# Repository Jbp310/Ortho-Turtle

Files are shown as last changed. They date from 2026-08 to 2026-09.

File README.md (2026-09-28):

# Ortho-Turtle

Ortho-Turtle is an ortholinear keyboard designed by me,  Fastturtle, for Hackclub's KEEB project.

**If you want to make this yourself, just grab the files from Production-Ready_Files, and you should be good to go.** 

# Design Philosophies:

Keyboard Layout:
I went for a fairly unique layout with this keyboard, as not only is it a ortholinear layout, but it's a fairly nonstandard amount of keys (81). My main motivator behind choosing the keys was having all the keys that I usually use, plus the ones that I would require to navigate an environment without a mouse, as I frequent janky linux distros.

PCB:
I designed my keyboard PCB fairly basically, as it's the first circuit board I've ever designed. I chose to use surface mount diodes, to give the keyboard a cleaner look, and to challenge my soldering skills a bit. Other than that though it's not particularly unique, although I'm quite happy with the design, especially with it being the first one I've made.

Case:
I chose to 3d print the case so that I could have more options when it comes to customizing it, additionally, it saves a lot of cost, as I'm able to use materials I have on hand, vs having to utilize grant funds. As for the actual case design I made a nice and simple tray mount, with a plate, to make it easier to 3d print. I plan on O-ring mounting the PCB to ensure a nicer, and more consistent typing experience.

# Things I learned:

I think the main lesson I learned throughout the development of this project was the importance of having a concrete idea of what you want before you start. As I could have saved a fair bit of time spent redesigning if I had just decided upon an idea to begin with. In addtition I also learned how to utilize KiCad.

# Credits

First of all, lots of thanks to Miles and the amazing team at Hackclub that helped put KEEB together, because without KEEB this project never would have been possible.

Secondly, thank you to Scotto Keebs for all the amazing guides on making custom keyboards.

Finally, me, I did design this whole keyboard, so you know, don't steal it, if have issues or questions just let me know, I'm always happy to help!

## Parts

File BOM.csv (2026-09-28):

Item | description | price | link
Keyboard Switches | Silent Tactile HMX Bluestar switches 90pcs | 33.26 | https://www.aliexpress.us/item/3256811672963963.html?curPageLogUid=IBwGcwixCsqs
Hotswap Sockets | Kailh hotswap sockets | 27.40 | https://www.aliexpress.us/item/3256804467765065.html?curPageLogUid=3ppgSUzBQ6wf
Screws | m3x10 screws for securing the PCB | 1.09 | https://www.aliexpress.us/item/3256808598917048.html?curPageLogUid=O4cSqPpW1uUs
Stabilizers | Screw in stabilizers for the keyboard | 1.09 | https://www.aliexpress.us/item/3256807050530252.html?curPageLogUid=OPPUPFXyg6cH
Keycaps | Double shot PBT keycaps for the keyboard | 9.64 | https://www.aliexpress.us/item/3256804350819353.html?curPageLogUid=l2Hzkh5qw7W4
PCB | The keyboard PCB | 24.30 | https://jlcpcb.com/
Orpheus Pico | Fancy Pi pico | unknown | N/A
Diodes | CDBW140-G Diodes from Comchip Technology SOD-123 Diodes | 14.29 | https://www.digikey.com/en/products/detail/comchip-technology/CDBW140-G/3308555

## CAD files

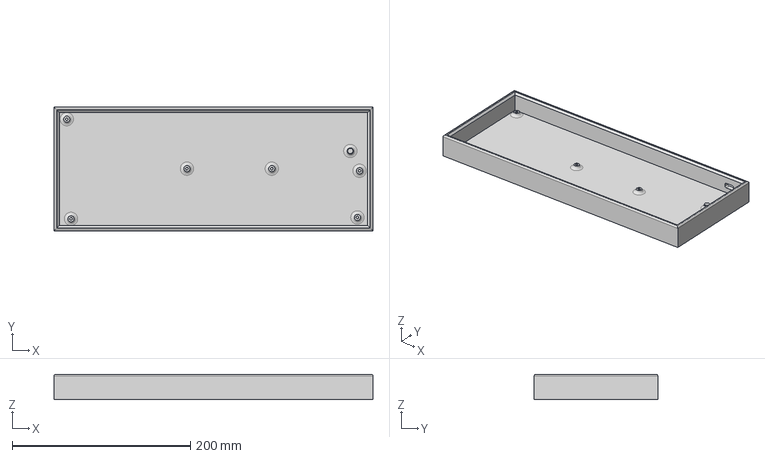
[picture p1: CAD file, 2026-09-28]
Case/Case.step
358.1 x 139.0 x 28.5 mm

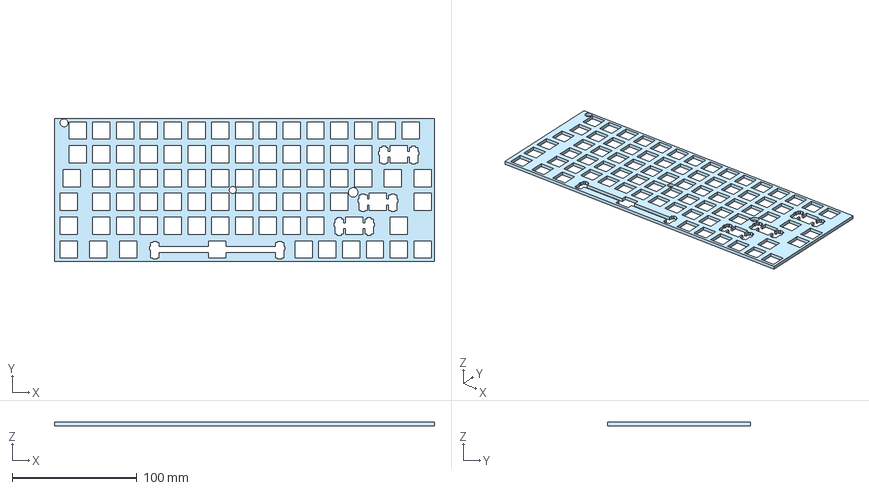
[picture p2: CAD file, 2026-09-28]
Case/Plate.step
304.2 x 114.3 x 3.00 mm

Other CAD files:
Production-Ready_Files/OrthoTurtle-Case.stl
Production-Ready_Files/Ortho-Turtle-Plate.stl

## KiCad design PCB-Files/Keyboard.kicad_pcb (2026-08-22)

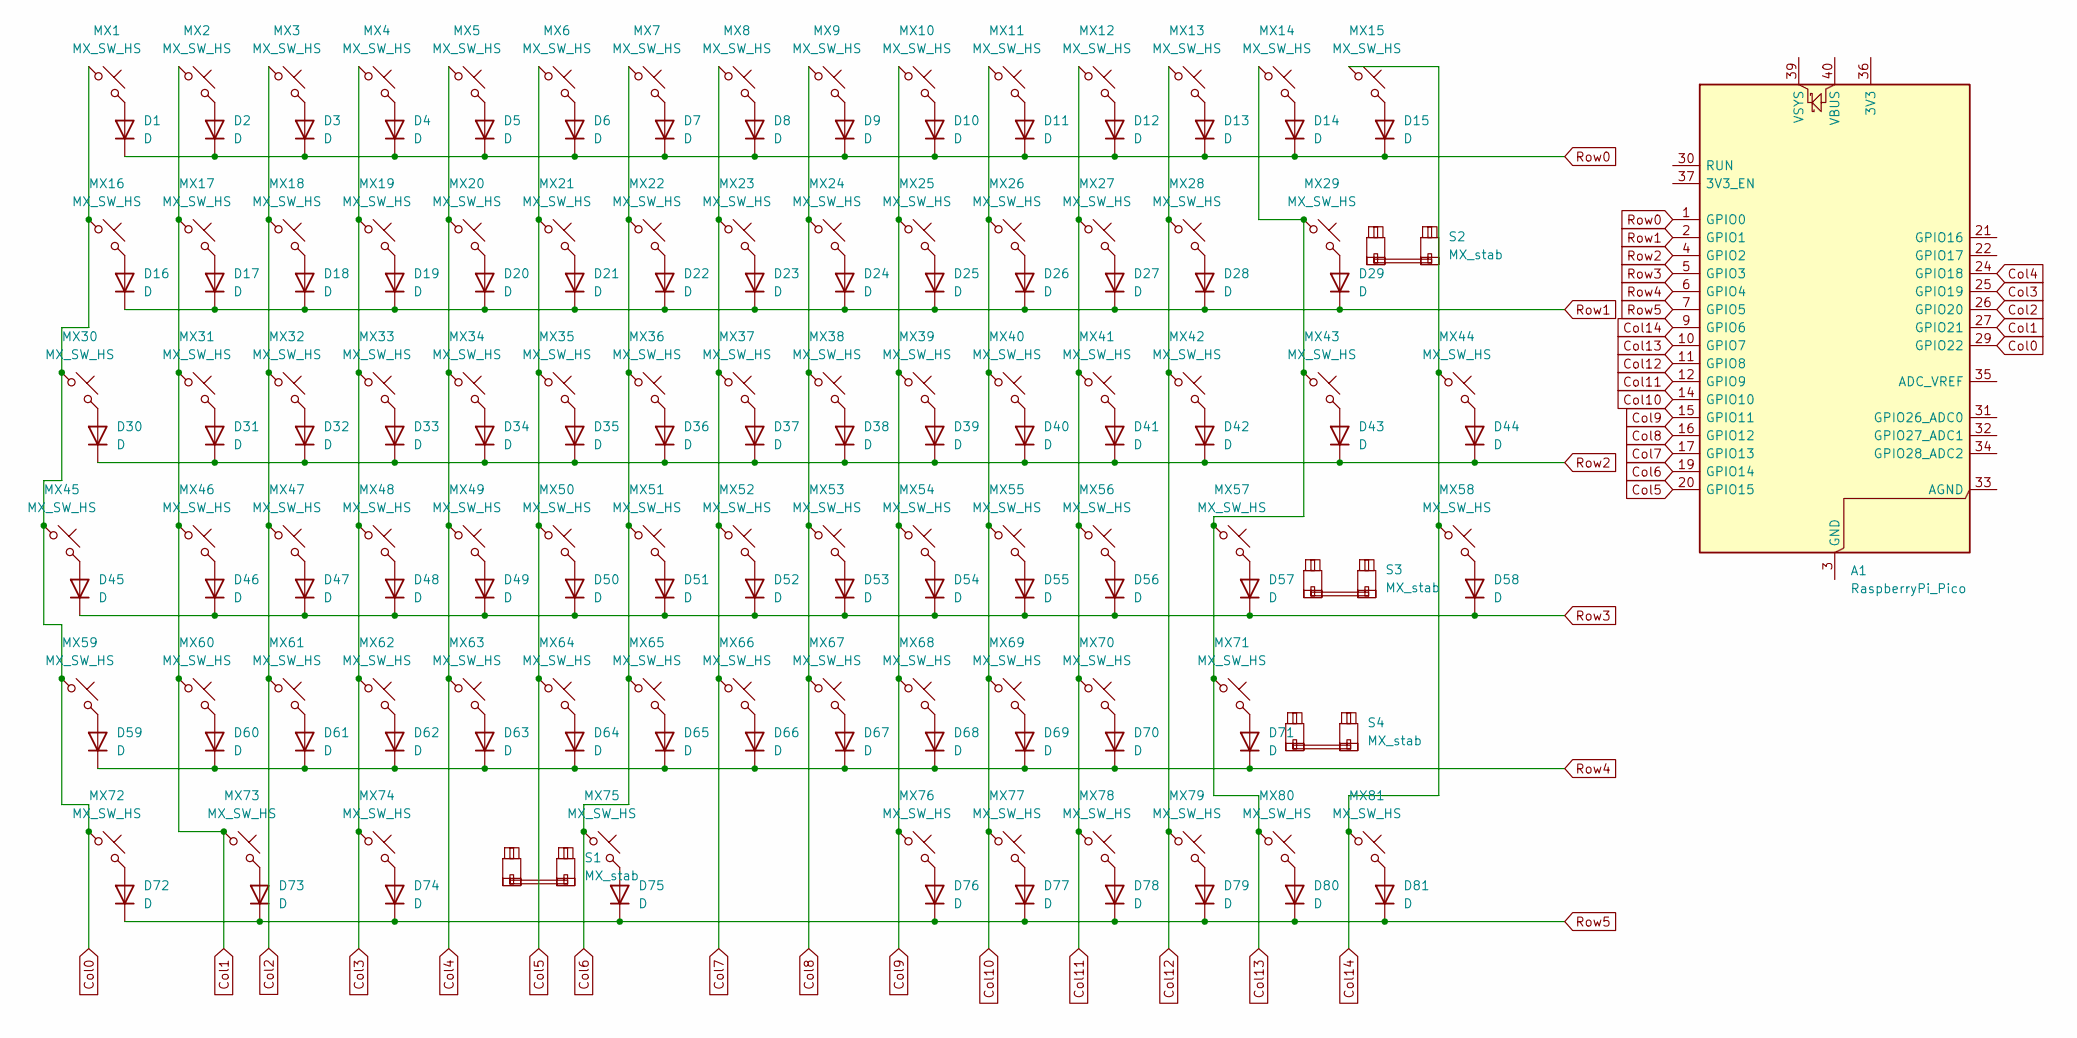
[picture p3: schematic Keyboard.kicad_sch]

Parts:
A1: RaspberryPi_Pico; RaspberryPi_Pico_Common_Unspecified
D1, D2, D3, D4, D5, D6, D7, D8, D9, D10, D11, D12, D13, D14, D15, D16, D17, D18, D19, D20, D21, D22, D23, D24, D25, D26, D27, D28, D29, D30, D31, D32, D33, D34, D35, D36, D37, D38, D39, D40, D41, D42, D43, D44, D45, D46, D47, D48, D49, D50, D51, D52, D53, D54, D55, D56, D57, D58, D59, D60, D61, D62, D63, D64, D65, D66, D67, D68, D69, D70, D71, D72, D73, D74, D75, D76, D77, D78, D79, D80, D81: D; D_SOD-123
MX1, MX2, MX3, MX4, MX5, MX6, MX7, MX8, MX9, MX10, MX11, MX12, MX13, MX14, MX15, MX16, MX17, MX18, MX19, MX20, MX21, MX22, MX23, MX24, MX25, MX26, MX27, MX28, MX29, MX30, MX31, MX32, MX33, MX34, MX35, MX36, MX37, MX38, MX39, MX40, MX41, MX42, MX43, MX44, MX45, MX46, MX47, MX48, MX49, MX50, MX51, MX52, MX53, MX54, MX55, MX56, MX57, MX58, MX59, MX60, MX61, MX62, MX63, MX64, MX65, MX66, MX67, MX68, MX69, MX70, MX71, MX72, MX73, MX74, MX75, MX76, MX77, MX78, MX79, MX80, MX81: MX_SW_HS; SW_MX_HS_CPG151101S11_1u
S1: MX_stab; STAB_MX_P_6.25u
S2: MX_stab; STAB_MX_P_2u
S3, S4: MX_stab; STAB_MX_P_2.25u

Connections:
Col0: A1.29 (GPIO22), MX1.1, MX16.1, MX30.1, MX45.1, MX59.1, MX72.1
Col1: A1.27 (GPIO21), MX2.1, MX17.1, MX31.1, MX46.1, MX60.1, MX73.1
Col2: A1.26 (GPIO20), MX3.1, MX18.1, MX32.1, MX47.1, MX61.1
Col3: A1.25 (GPIO19), MX4.1, MX19.1, MX33.1, MX48.1, MX62.1, MX74.1
Col4: A1.24 (GPIO18), MX5.1, MX20.1, MX34.1, MX49.1, MX63.1
Col5: A1.20 (GPIO15), MX6.1, MX21.1, MX35.1, MX50.1, MX64.1
Col6: A1.19 (GPIO14), MX7.1, MX22.1, MX36.1, MX51.1, MX65.1, MX75.1
Col7: A1.17 (GPIO13), MX8.1, MX23.1, MX37.1, MX52.1, MX66.1
Col8: A1.16 (GPIO12), MX9.1, MX24.1, MX38.1, MX53.1, MX67.1
Col9: A1.15 (GPIO11), MX10.1, MX25.1, MX39.1, MX54.1, MX68.1, MX76.1
Col10: A1.14 (GPIO10), MX11.1, MX26.1, MX40.1, MX55.1, MX69.1, MX77.1
Col11: A1.12 (GPIO9), MX12.1, MX27.1, MX41.1, MX56.1, MX70.1, MX78.1
Col12: A1.11 (GPIO8), MX13.1, MX28.1, MX42.1, MX79.1
Col13: A1.10 (GPIO7), MX14.1, MX29.1, MX43.1, MX57.1, MX71.1, MX80.1
Col14: A1.9 (GPIO6), MX15.1, MX44.1, MX58.1, MX81.1
unnamed: A1.3 (GND), A1.8 (GND), A1.13 (GND), A1.18 (GND), A1.23 (GND), A1.28 (GND), A1.38 (GND)
unnamed: D1.2 (A), MX1.2
unnamed: D2.2 (A), MX2.2
unnamed: D3.2 (A), MX3.2
unnamed: D4.2 (A), MX4.2
unnamed: D5.2 (A), MX5.2
unnamed: D6.2 (A), MX6.2
unnamed: D7.2 (A), MX7.2
unnamed: D8.2 (A), MX8.2
unnamed: D9.2 (A), MX9.2
unnamed: D10.2 (A), MX10.2
unnamed: D11.2 (A), MX11.2
unnamed: D12.2 (A), MX12.2
unnamed: D13.2 (A), MX13.2
unnamed: D14.2 (A), MX14.2
unnamed: D15.2 (A), MX15.2
unnamed: D16.2 (A), MX16.2
unnamed: D17.2 (A), MX17.2
unnamed: D18.2 (A), MX18.2
unnamed: D19.2 (A), MX19.2
unnamed: D20.2 (A), MX20.2
unnamed: D21.2 (A), MX21.2
unnamed: D22.2 (A), MX22.2
unnamed: D23.2 (A), MX23.2
unnamed: D24.2 (A), MX24.2
unnamed: D25.2 (A), MX25.2
unnamed: D26.2 (A), MX26.2
unnamed: D27.2 (A), MX27.2
unnamed: D28.2 (A), MX28.2
unnamed: D29.2 (A), MX29.2
unnamed: D30.2 (A), MX30.2
unnamed: D31.2 (A), MX31.2
unnamed: D32.2 (A), MX32.2
unnamed: D33.2 (A), MX33.2
unnamed: D34.2 (A), MX34.2
unnamed: D35.2 (A), MX35.2
unnamed: D36.2 (A), MX36.2
unnamed: D37.2 (A), MX37.2
unnamed: D38.2 (A), MX38.2
unnamed: D39.2 (A), MX39.2
unnamed: D40.2 (A), MX40.2
unnamed: D41.2 (A), MX41.2
unnamed: D42.2 (A), MX42.2
unnamed: D43.2 (A), MX43.2
unnamed: D44.2 (A), MX44.2
unnamed: D45.2 (A), MX45.2
unnamed: D46.2 (A), MX46.2
unnamed: D47.2 (A), MX47.2
unnamed: D48.2 (A), MX48.2
unnamed: D49.2 (A), MX49.2
unnamed: D50.2 (A), MX50.2
unnamed: D51.2 (A), MX51.2
unnamed: D52.2 (A), MX52.2
unnamed: D53.2 (A), MX53.2
unnamed: D54.2 (A), MX54.2
unnamed: D55.2 (A), MX55.2
unnamed: D56.2 (A), MX56.2
unnamed: D57.2 (A), MX57.2
unnamed: D58.2 (A), MX58.2
unnamed: D59.2 (A), MX59.2
unnamed: D60.2 (A), MX60.2
unnamed: D61.2 (A), MX61.2
unnamed: D62.2 (A), MX62.2
unnamed: D63.2 (A), MX63.2
unnamed: D64.2 (A), MX64.2
unnamed: D65.2 (A), MX65.2
unnamed: D66.2 (A), MX66.2
unnamed: D67.2 (A), MX67.2
unnamed: D68.2 (A), MX68.2
unnamed: D69.2 (A), MX69.2
unnamed: D70.2 (A), MX70.2
unnamed: D71.2 (A), MX71.2
unnamed: D72.2 (A), MX72.2
unnamed: D73.2 (A), MX73.2
unnamed: D74.2 (A), MX74.2
unnamed: D75.2 (A), MX75.2
unnamed: D76.2 (A), MX76.2
unnamed: D77.2 (A), MX77.2
unnamed: D78.2 (A), MX78.2
unnamed: D79.2 (A), MX79.2
unnamed: D80.2 (A), MX80.2
unnamed: D81.2 (A), MX81.2
Row0: A1.1 (GPIO0), D1.1 (K), D2.1 (K), D3.1 (K), D4.1 (K), D5.1 (K), D6.1 (K), D7.1 (K), D8.1 (K), D9.1 (K), D10.1 (K), D11.1 (K), D12.1 (K), D13.1 (K), D14.1 (K), D15.1 (K)
Row1: A1.2 (GPIO1), D16.1 (K), D17.1 (K), D18.1 (K), D19.1 (K), D20.1 (K), D21.1 (K), D22.1 (K), D23.1 (K), D24.1 (K), D25.1 (K), D26.1 (K), D27.1 (K), D28.1 (K), D29.1 (K)
Row2: A1.4 (GPIO2), D30.1 (K), D31.1 (K), D32.1 (K), D33.1 (K), D34.1 (K), D35.1 (K), D36.1 (K), D37.1 (K), D38.1 (K), D39.1 (K), D40.1 (K), D41.1 (K), D42.1 (K), D43.1 (K), D44.1 (K)
Row3: A1.5 (GPIO3), D45.1 (K), D46.1 (K), D47.1 (K), D48.1 (K), D49.1 (K), D50.1 (K), D51.1 (K), D52.1 (K), D53.1 (K), D54.1 (K), D55.1 (K), D56.1 (K), D57.1 (K), D58.1 (K)
Row4: A1.6 (GPIO4), D59.1 (K), D60.1 (K), D61.1 (K), D62.1 (K), D63.1 (K), D64.1 (K), D65.1 (K), D66.1 (K), D67.1 (K), D68.1 (K), D69.1 (K), D70.1 (K), D71.1 (K)
Row5: A1.7 (GPIO5), D72.1 (K), D73.1 (K), D74.1 (K), D75.1 (K), D76.1 (K), D77.1 (K), D78.1 (K), D79.1 (K), D80.1 (K), D81.1 (K)

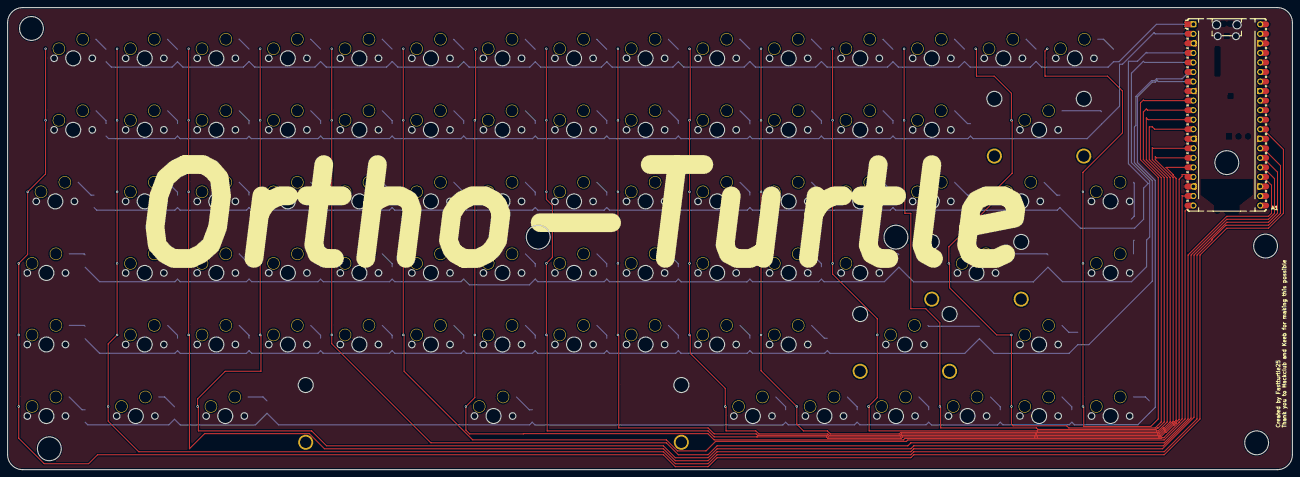
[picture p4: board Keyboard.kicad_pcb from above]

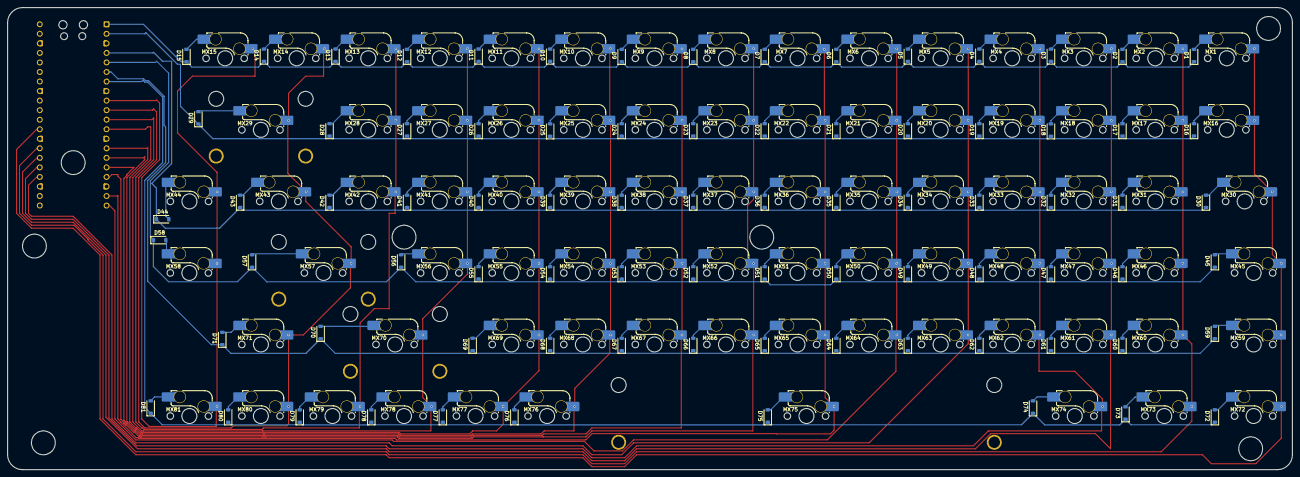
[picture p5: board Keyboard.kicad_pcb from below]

Board: 2 copper layers, 342.1 x 123.0 mm, 167 parts (162 on the bottom side), 103 nets.

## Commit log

2026-08-19 Adding all of the PCB Files
    This should be all of the PCB files, hopefully they're okay.
    [Keyboard-B_Cu.gbr, Keyboard-B_Mask.gbr, Keyboard-B_Paste.gbr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]
2026-08-19 Creating folder for PCB files
2026-08-19 Reorganizing PCB-Files
    All I did was just put them in their own folder
    [Keyboard-B_Cu.gbr, Keyboard-B_Mask.gbr, Keyboard-B_Paste.gbr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]
2026-08-21 Updating the PCB design
    I updated the PCB design this should hopefully fix some of the issues I was having
    [Keyboard-B_Cu.gbr, Keyboard-B_Mask.gbr, Keyboard-B_Paste.gbr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]
2026-08-22 Final PCB fixes
    These should be the final fixes for the PCB including fixing the Pi picos grounding and doing logos
    [Keyboard-B_Cu.gbr, Keyboard-B_Mask.gbr, Keyboard-B_Paste.gbr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]
2026-09-26 Final PCB files
    Generated the Final PCB files, there shouldn't be much new, but they're in the requested format now.
    [Keyboard-B_Cu.gbr, Keyboard-B_Mask.gbr, Keyboard-B_Paste.gbr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]
2026-09-26 Submitting Case Files
    Submitting the Case files, this should be one of the final steps before project submission.
    [Ortho-Turtle-Plate.stl, OrthoTurtle-Case.stl]
2026-09-26 Created The Bill of Materials
    Uploaded and created the Bill of Materials, per Keeb guidlines.
    [BOM.csv]
2026-09-26 Updated BOM
    Forgot somethings on the BOM
    [BOM.csv]
2026-09-28 Rearrange files
    [Case.step, Ortho-Turtle-Plate.stl, OrthoTurtle-Case.stl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]
